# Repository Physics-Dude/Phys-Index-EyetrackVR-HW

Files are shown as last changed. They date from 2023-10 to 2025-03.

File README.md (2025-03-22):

# Phys-Index-EyetrackVR-HW
Custom solution for a clean, unobtrusive, EyeTrackVR installation in the **Valve Index**.  

### Project includes:
- Custom, highly iterated camera and LED mounts based on bitbyt3r's design that may be preferable to any builder. Supports most OV2640 cameras with an 8mm square, 2mm tall base.
- All-in-one dongle that carries a USB hub, 2x XIAO ESP32s, the ETVR v4 PCB, and an extra USB port.

Everything fits entirely within the envelope of the Valve Index. No modifications to the Valve Index headset are required whatsoever; just some clever cable routing. 

newnewnewnwe

### NEW! Gum Stick Remix (GSR) by Renzath
- Supports an aditional ESP for face tracking, and uses a different USB hub.
- Full writeup TBD

  Photo TBD

# Build the Original Gumstick Project! 

## Camera and LED mounts
An evolution of bitbyt3r's index-eyetrackvr mounts for the Valve Index found here: https://github.com/bitbyt3r/index-eyetrackvr  

cad-shot

Light pattern:


Files: https://github.com/Physics-Dude/Phys-Index-EyetrackVR-HW/tree/main/ETVR%20ValveIndex%20Cam-LED%20Mount%20Rings

### Changes:
- Lowered all leds 0.5mm further from face.
- Thickened up thin points near LEDs so they are FDM-printable in a single fill-line.
- Chamfers and fillets for strength and comfort.
- Tweaked the fit on the LED posts to prevent binding on solderless kits.
- Moved the camera up to the side of the eye.
- Moved the all the LEDs to a more optimal position to prevent specular reflections, shadows, and silhouetting.
### Tips:
- Print in black PETG
- Mirror the provided file for the opposite eye
- If you need to extend the wires a bit, stagger your cuts to prevent the joints from ever touching.

## Gum Stick USB Hub Dongle
Built around a specific ultra-slim 3-port USB hub. Fits two XIAO ESP32-S3s and a ETVR v4 PCB, as well as a spare USB port.

Files: https://github.com/Physics-Dude/Phys-Index-EyetrackVR-HW/tree/main/Gum%20Stick%20Dongle%20Custom%20USB%20Hub%20Case



### You need this specific USB hub (various brands)
Found on the likes of Amazon and Aliexpress. Its easy to modify for our purpose.



#### Common Titles:
- "USB Hub 3.0 Extender 3-Port, sartyee Computer Networking Hubs for MacBook, Mac Pro, iMac, Ps4/5, Surface Pro,Flash Drive, Keyboard, Mouse, Windows"
- "3 Ports Multiple Expander with 1 USB3.0 and 2 USB2.0 Ports Type-C3.0/USB3.0 To 3USB HUB Ultra Slim Splitter 480Mbps-5.0Gbps"
- "3 Port USB 3.0 USB Hub 2.0 Multi Type-C Ultra Slim Splitter Hub Use Power Adapter Multiple Expander 2.0 USB 3.0 Hub for PC"
#### Links:
- ~~Amazon: https://www.amazon.com/gp/product/B0BQ68QGYJ/~~ (Listing updated and now shows similar but different product.)
- Amazon: https://www.amazon.com/YaimhSound-Extender-Splitter-Extension-Keyborad/dp/B0BXJ21DXZ
- Aliexpress (choose the normal USB version): https://www.aliexpress.us/item/3256805344126437.html
#### Note/Avoid: 
- Avoid similar looking USB hubs with an LED indicator present between the two side-mounted ports. These likely won't fit since the PCB design on these seems to be flipped. If you do come across one such USB hub, consider using the (currently untested) no-spacer alternitive which gives you about 1mm of room to route soldered wires under the hub's PCB. [Gum Stick Dongle Custom USB Hub Case/No-Spacer alternate - XIAO-ESP32S3 ETVR v4 gum stick index mount v24.stl](https://github.com/Physics-Dude/Phys-Index-EyetrackVR-HW/blob/main/Gum%20Stick%20Dongle%20Custom%20USB%20Hub%20Case/No-Spacer%20alternate%20-%20XIAO-ESP32S3%20ETVR%2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) 

### You want these other parts too
- 2x XIAO ESP32-S3 Sense Modules - https://www.seeedstudio.com/XIAO-ESP32S3-Sense-p-5639.html
- 1x Solder-less V4 kit - https://store.eyetrackvr.dev/products/v4-mini-fully-solderless-kit
- Misc 28-32AWG wire for lengthening LED power wires
- 7x M2x5mm Countersink Self-tapping screws
- 2x OV2640 160 degrees night version camera module 200MM (select 200MM night vision) - https://www.aliexpress.us/item/3256803720134565.html - https://www.aliexpress.us/item/3256804483974787.html
  


Additional hardware options with more links available in the EyeTrackVR docs: https://docs.eyetrackvr.dev/how_to_build/parts_list

## Assemble it!
Follow the EyetrackVR docs for primary assembly and programming: https://docs.eyetrackvr.dev/how_to_build/full_build

Steps specific to the dongle are as follows.

### 1. Print 
- Print all 3 parts of the Gumstick in PETG
  - Files: https://github.com/Physics-Dude/Phys-Index-EyetrackVR-HW/tree/main/Gum%20Stick%20Dongle%20Custom%20USB%20Hub%20Case
- Print a Left and Right pair of the camera/LED mount rings if you have not already/
  - Files: https://github.com/Physics-Dude/Phys-Index-EyetrackVR-HW/tree/main/ETVR%20ValveIndex%20Cam-LED%20Mount%20Rings
- Refer or use the "PRINT ME" file for suggested orientations.
- ENABLE SUPPORT MATERIAL on build plate only.

### 2. Mod the USB hub
- Take the aforementioned USB hub apart (it slides out when you plug something in the end with a little force) and de-solder all the connectors. Save at least one of the small USB 2.0 ones.
- If the case is stuck, you may have to get a Dremel or some snips and nip away at the corners, careful not to cut the PCB. It is only glued near the input USB.
- I suggest using a hot air tool if possible to remove the connectors. Adding your own flux and leaded solder will make desoldering easier too regardless.

Untitled-1pin

### 3. Place
- Insert your dismantled USB hub into the dongle along with the spare USB port. Make sure you removed all the support material in that cavity. 
- Verify that your XIAO ESPs and ETVR v4 PCB fit in their slots. It may be tight, but if not, use adhesives. Careful not to crush the ESP's buttons or riser connector!
  


### 4. Solder
- Solder your VUSB, GND, D+ and D- wires to your ESPs now.
- Use the square ground pad on the bottom of the XIAO ESP for ground (not the GND pin on the edge of the board). 
- Observe the Connector orientation of the original USB hub and refrence it to a pin-out diagram of the USB A port. 
- Solder 2 wires to the bottom side of the ETVR v4 PCB for power. (and led wires for solder-kit)
- Route them like so and solder in place. A small hole will let you route the ETVR v4 PCB wires into the main cavity.
  



- quick wiring diagram to mitigate confusion


- Still confused? This diagram might help: https://github.com/Physics-Dude/Phys-Index-EyetrackVR-HW/issues/5#issuecomment-2413598211

### 6. LEDs!
- You will follow the instructions in the ETVR docs and lengthen a couple of the wires with 36-32awg wire.
- The long main feed wires get extended to about 200-250mm, while two of the shorter wires get extended to about 80mm.
- Tip: Stagger your cuts when lengthening your wires so the soldered ends can never touch.

- Once you verify everyhting is working 100%, it might be a good idea to remove the unused connectors on the E/End LEDs. You can do this with a pair of snips and a soldering iron with fresh solder.  



(early version of the modified mounts)


(latest version close up, installed )
anotehr-new-bpic

### 7. Cable Routing
- Your 200mm camera ribbons can be pushed up the "nose" of the headset and around the top of the PCB.

PXL_20231018_004047633s

- They may seem to interfere with IPD adjustment, but try folding them so they take a twist as they travel behind the PCB and between the screens. Keep in mind you may loose a couple millimeters of IPD due to the LED placement when using solder-less kit.
- Then they can be massaged through the vent holes in the frunk along with the extended LED power wires.



- It might help to gently fold your ribbon cable like so to get it to fit in the frunk vent holes. Note that some vent slots are blocked when assembled. 



- Pinch point! Watch here when the face pad is mounted. It's possible the ribbon cable can get trapped under this lip when adjusting screen-face distance. A small bend in the wire will teach it to stay away.
  
pibce 

- I also found that folding the camera ribbons like so can help teach them where to go.
  
teach

### 8. Finalizing
- Plug everything in and secure the optional covers with M2x5mm Countersink Self-tapping screws.
- P.S. Did you notice the holes for a 25mm fan? Is optional, but there if you want to keep your ESPs chilly.




- Use a Command Strip or piece of foam to ensure dongle does not come out during extreme VR stunts.
- Big nose? Consider removing the unused connector on the End LED if you expierence contact in that area. Felt may also be added for comfort.
nose-bridge

### Camera mount for Babble Face Tracking (uses same ESPs and Cameras)
- This part is in development, but working nicely from the start. You'll have to observe the pictures below to duplicate the build for your specific hardware.
- Files: https://github.com/Physics-Dude/Phys-Index-EyetrackVR-HW/tree/main/Babble%20Face%20Tracker%20Cam-LED%20Mount



extendd-mount


## In (experimental) summary:
- Use the same XIAO ESPs, with the same OpenIris firmware as the eye trackers.
- Use the same 200mm long OV2640 160 degrees night version IR camera module.
- Use two 3mm IR LEDs wired in series with a 100R resister on the 5v VBUS rail (use the 3V3 rail or a larger value resistor if you have more efficient LEDs). I sanded the lenses down on my leds for a wider, softer spread as well. 
- 3D print the print file in the Babble Face Tracker Cam-LED Mount folder with support material enabled. (EXTENDED version also available, print both to see what works for you)
- Stick camera mount base and cable clip to your Valve Index with double-sided VHB tape as shown.
- Use a 25mm countersink M3 screw with lock nut for the hinge.
- XIAO ESP can be placed at the end of the Gum Stick with more VBH tape.

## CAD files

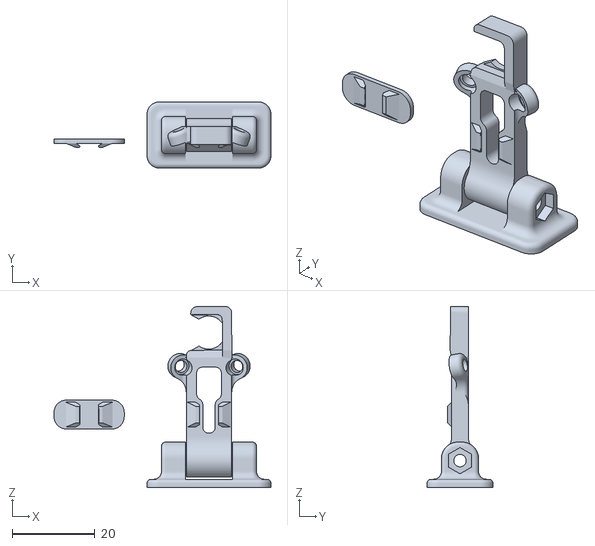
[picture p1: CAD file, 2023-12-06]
Babble Face Tracker Cam-LED Mount/FACE MOUNT v4 assembled.stl
52.5 x 16.0 x 43.8

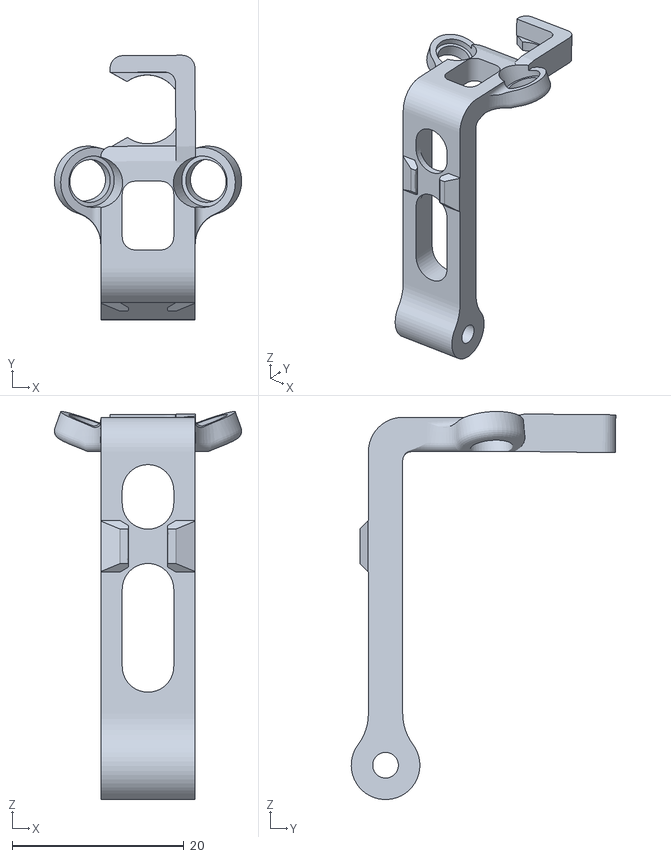
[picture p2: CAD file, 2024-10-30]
Babble Face Tracker Cam-LED Mount/EXTENDED Face Mount arm v5 - supports 5mm leds.stl.stl
21.8 x 30.8 x 45.2

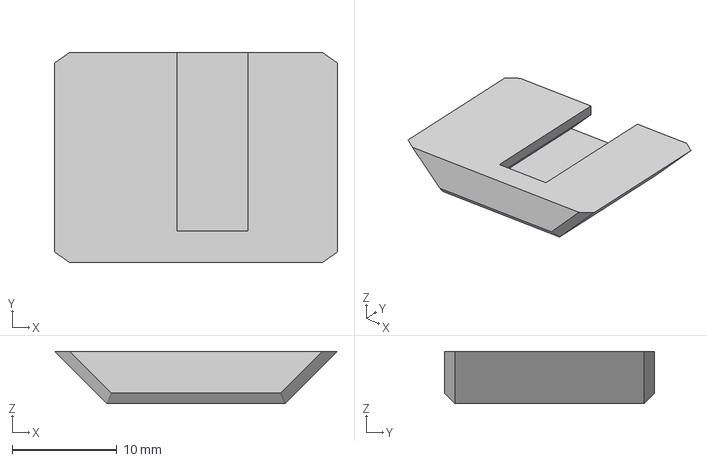
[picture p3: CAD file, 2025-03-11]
Babble Face Tracker Cam-LED Mount/Gumstick Remix Mount (Alternative)/GSR_Babble_FaceCam_Base.3mf
27.0 x 20.0 x 5.00 mm

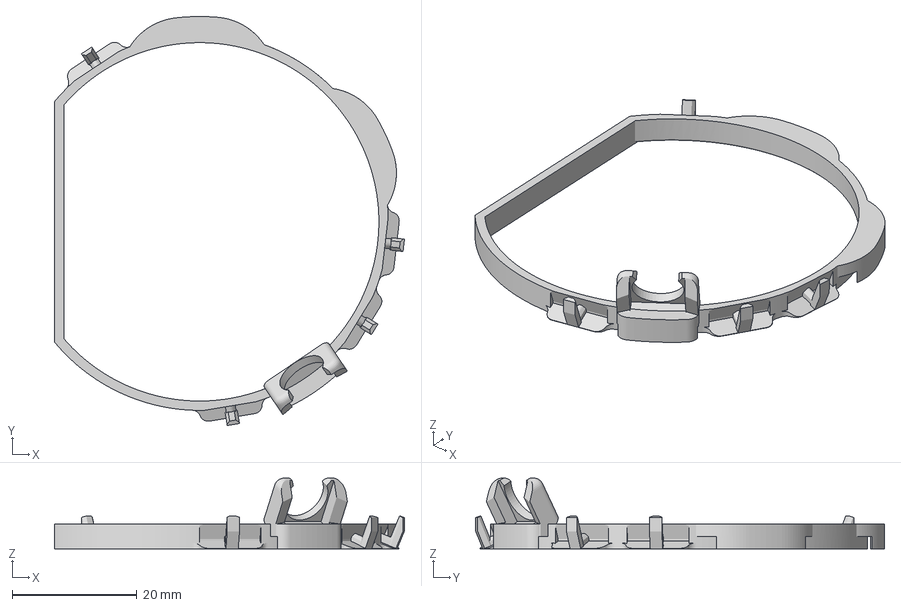
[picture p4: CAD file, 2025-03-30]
ETVR ValveIndex Cam-LED Mount Rings/Index-EyetrackVRv4 (GSR_Alt).3mf
56.2 x 65.6 x 11.3 mm

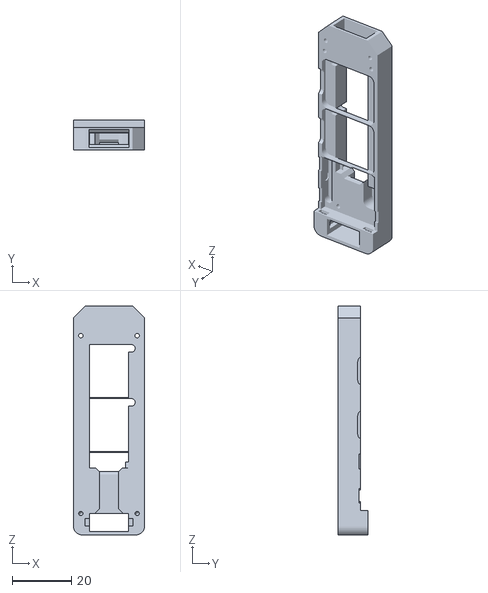
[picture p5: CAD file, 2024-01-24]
Gum Stick Dongle Custom USB Hub Case/No-Spacer alternate - XIAO-ESP32S3 ETVR v4 gum stick index mount v24.stl
24.0 x 10.0 x 77.2

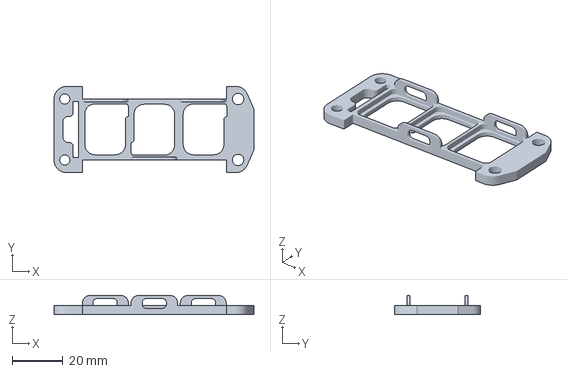
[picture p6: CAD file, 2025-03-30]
Gum Stick Remix for 3x ESPs plus USB Hub/Adafruit USB Hub (Latest Version)/GSR-Adafruit_ESP-Frame-Basic.3mf
78.8 x 34.0 x 7.50 mm

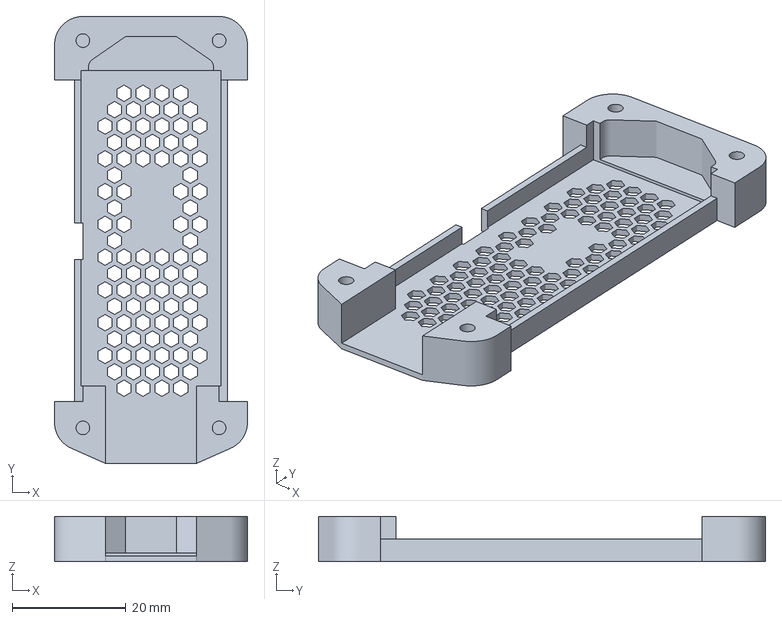
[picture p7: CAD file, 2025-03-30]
Gum Stick Remix for 3x ESPs plus USB Hub/Adafruit USB Hub (Latest Version)/Prototypes (Work In Progress)/GSR-Adafruit_THD-Base-Cover.3mf
34.0 x 78.8 x 8.00 mm

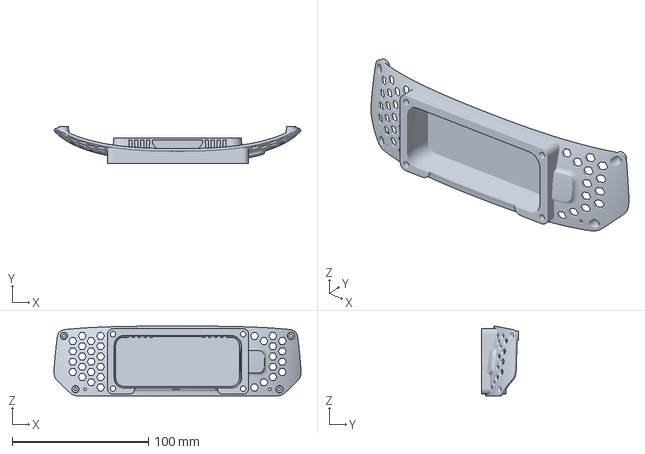
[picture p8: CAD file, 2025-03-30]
Gum Stick Remix for 3x ESPs plus USB Hub/Frunk Holder (Use M3x14mm Lid)/GSR-Frunk_Index-Frame.3mf
181.5 x 27.2 x 51.3 mm

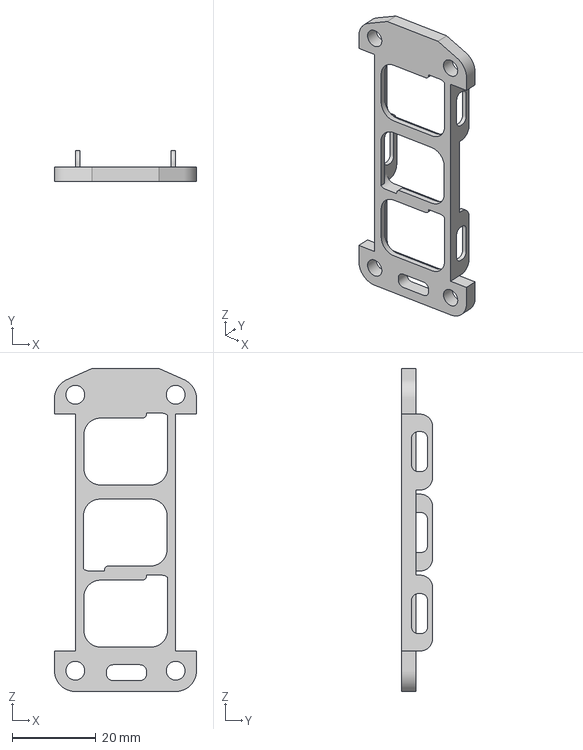
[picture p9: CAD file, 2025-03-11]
Gum Stick Remix for 3x ESPs plus USB Hub/Origional GSR Design (Cheap USB Hub)/GSR-Origional_ESP-Frame.3mf
34.0 x 7.50 x 77.3 mm

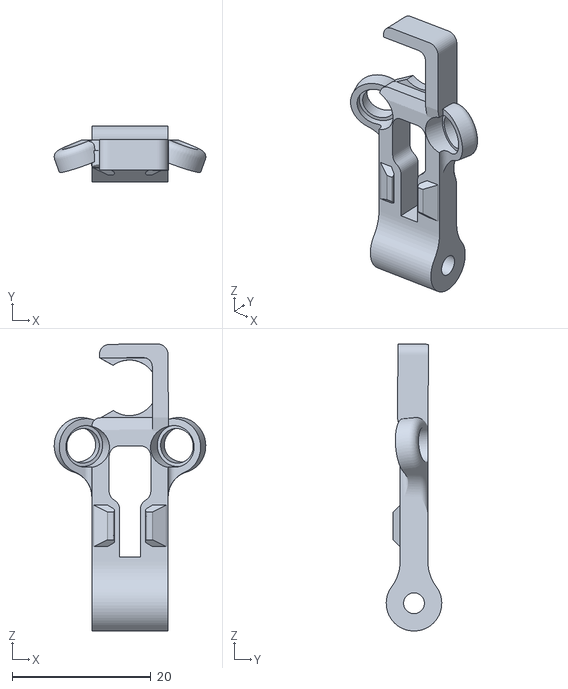
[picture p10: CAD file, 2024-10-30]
Babble Face Tracker Cam-LED Mount/Face Mount arm v5 - supports 5mm leds.stl
21.8 x 7.99 x 41.3

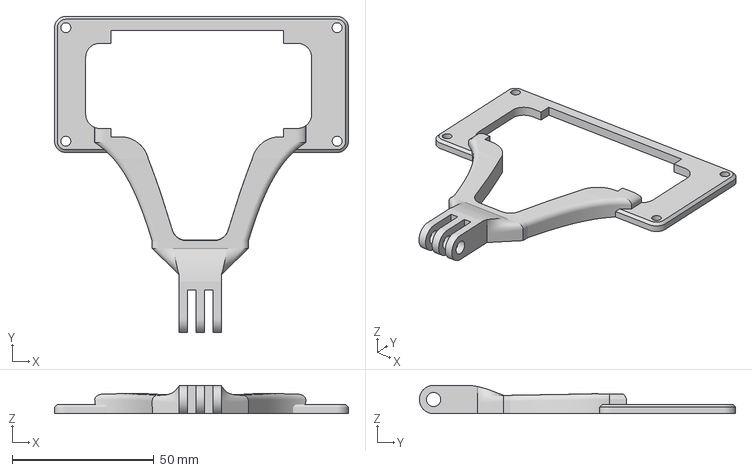
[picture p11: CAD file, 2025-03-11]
Babble Face Tracker Cam-LED Mount/Gumstick Remix Mount (Alternative)/GSR_Basic_FaceCam-Module.3mf
103.6 x 111.5 x 10.0 mm

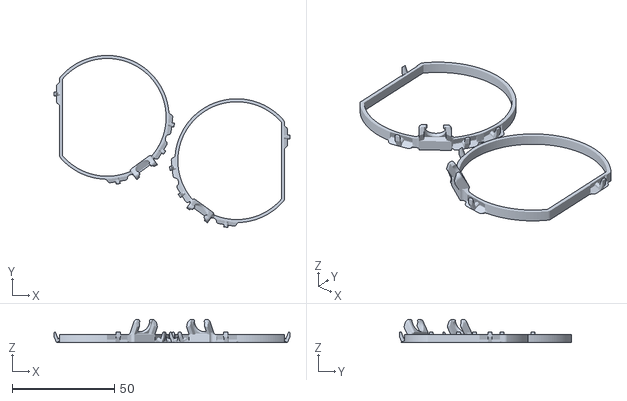
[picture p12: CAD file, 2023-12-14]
ETVR ValveIndex Cam-LED Mount Rings/Index-EyetrackVRv4 v18 combined L and R plate.stl
115.3 x 84.1 x 11.3

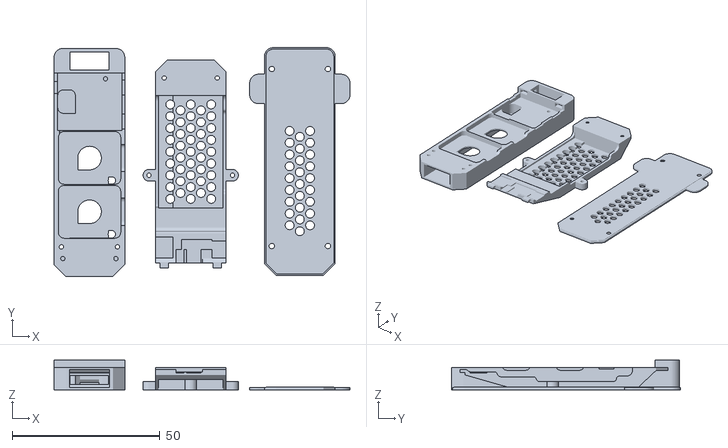
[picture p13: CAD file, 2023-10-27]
Gum Stick Dongle Custom USB Hub Case/XIAO-ESP32S3 ETVR v4 gum stick index mount v22 PRINT ME.stl
100.3 x 77.5 x 10.0

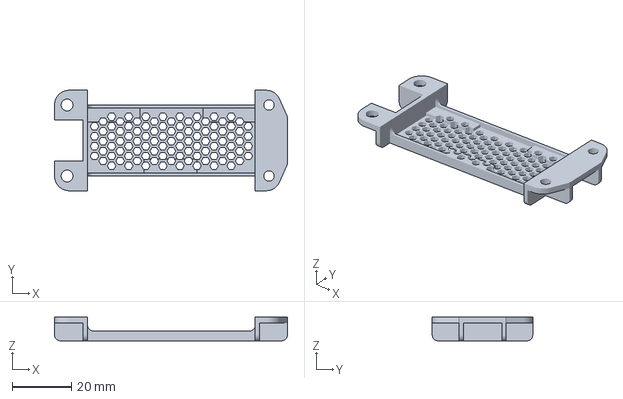
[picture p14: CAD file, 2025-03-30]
Gum Stick Remix for 3x ESPs plus USB Hub/Adafruit USB Hub (Latest Version)/GSR-Adafruit_Lid-Cover-USB (M3x14mm).3mf
78.8 x 34.0 x 8.00 mm

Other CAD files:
Gum Stick Remix for 3x ESPs plus USB Hub/Adafruit USB Hub (Latest Version)/Prototypes (Work In Progress)/GSR-Adafruit_Lid-Cover-USB (M3x20mm).3mf
Gum Stick Remix for 3x ESPs plus USB Hub/Frunk Holder (Use M3x14mm Lid)/GSR-Frunk_Brace_NoCam.3mf
Gum Stick Remix for 3x ESPs plus USB Hub/Origional GSR Design (Cheap USB Hub)/GSR-Origional_Hub-Frame.3mf
Babble Face Tracker Cam-LED Mount/EXTENDED Face Mount arm v4 PRINT ME.stl
Babble Face Tracker Cam-LED Mount/FACE MOUNT v4 - PRINT ME with support.stl
Babble Face Tracker Cam-LED Mount/Gumstick Remix Mount (Alternative)/GSR_Babble_FaceCam_Left.3mf
Babble Face Tracker Cam-LED Mount/Gumstick Remix Mount (Alternative)/GSR_Babble_FaceCam_Right.3mf
Babble Face Tracker Cam-LED Mount/Gumstick Remix Mount (Alternative)/GSR_Basic_FaceCam-Mount.3mf
ETVR ValveIndex Cam-LED Mount Rings/Index-EyetrackVRv4 (GSR_Alt).f3d
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

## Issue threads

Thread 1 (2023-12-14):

right eye print

rawpie2, 2023-12-14:
I only see left eye in the .stl files, where is the one to print for the right eye? thanks.

Physics-Dude, 2023-12-14:
You have to mirror the model in your slicer to print the right eye ring. (In Prusa Slicer for example, right click the part > Mirror > Mirror X).
This simplifies version control and encourages you to print one ring at a time which reduces stringing.

Physics-Dude, 2023-12-14:
I created [ETVR ValveIndex Cam-LED Mount Rings/Index-EyetrackVRv4 v18 combined L and R plate.stl](https://github.com/Physics-Dude/Phys-Index-EyetrackVR-HW/blob/d3e680a5e1266e084980f29253d3a4de4e84feea/ETVR%20ValveIndex%20Cam-LED%20Mount%20Rings/Index-EyetrackVRv4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) with both mirrored copies of the rings if desired. Just be careful on stringy printers.

Closed 2023-12-14.

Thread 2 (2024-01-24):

[Model question] "Inverted" gum stick model

tompointexe, 2024-01-24:
Hi, with the usb hub i got, mounting and solderiung would result in the boards beeing on the wrong side, do you have a model with is "inverted" from the curent one, see pics below
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

Thanks a lot

Physics-Dude, 2024-01-24:
That is weird. I've never came across that model of USB hub before. Do you have a link to the product pace so we can avoid that in the future? It looks like it has an LED in the middle which might be a good indicator for future product hunts.

A mirrored version wont work since all your solder pads will still effectively be on the wrong side of the USB hub's PCB. You might be better off soldering your thinnest wire (28-32AWG) to all the hub pads you'll need, then sliding it into the gum stick you already printed so those pads are effectively facing downwards and hidden.

Alternatively, here is a version of the hum stick that has the spacer between the ESPs and USB hub PCB removed. This should give you more room for the soldered pads and wire to snake out from under the usb hub's pcb and into the cavity for later connection to the ESPs. I'd suggest a strip of tape on the ESPs though to prevent any shorts if you dont trust your soldering.

[No-Spacer alternate - XIAO-ESP32S3 ETVR v4 gum stick index mount v24.stl](https://github.com/Physics-Dude/Phys-Index-EyetrackVR-HW/blob/main/Gum%20Stick%20Dongle%20Custom%20USB%20Hub%20Case/No-Spacer%20alternate%20-%20XIAO-ESP32S3%20ETVR%2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)

Keep us updated so we can mention it in the doc.

tompointexe, 2024-01-24:
Yup inverted is not realy the term, it would need to have the pcb insert and usb port where the front facing usb port is, and put that where the curent hub pcb insert is
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

The hub i've used is this one, it's the only one i could find on amazon.fr / Europe, i've not searched aliexpress tho
https://www.amazon.fr/dp/B0CLY9KZ68?

Physics-Dude, 2024-01-24:
The way I understand it, flipping the whole gum stick model on X or Y, (or inserting the hub from the other direction as per your initial edit) will not expose the HUB's solder pads since those are referenced to the orientation of the main USB port that plugs into the headset.

I would personally buy the correct hub from aliexpress. Re-mounting the main port sounds too invasive considering its molded into plastic from the factory.

The No-Spacer alternate body I linked previously does give you about 1mm of room to solder and route wires from 'under' the usb hub pcb to anywhere else in the cavity of the gum stick (as long as you solder the wires before inserting the hub into the main body of the gum stick with the corrected orientation). If you got the time waiting for a new hub, I'd still try this so at least you'd have a working spare if it doesn't work out.

I'll put a note in the readme to avoid the similar-looking USB hubs with LED indicators.

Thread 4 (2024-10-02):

(tweak) Please consider adding a license

dfgHiatus, 2024-10-02:
I am thinking of using the Babble 3D models for an assembly animation. I wanted to confirm this was suitable with you for our use case.

Physics-Dude, 2024-10-02:
Sounds cool to me! Go for it.
I'll go ahead and add the MIT License unless someone has an alternate suggestion.

Physics-Dude, 2024-10-02:
added https://github.com/Physics-Dude/Phys-Index-EyetrackVR-HW/blob/main/LICENSE

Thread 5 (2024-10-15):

confused about the soldering

fleufy, 2024-10-15:
Hi! It's my first time doing this sort of thing, I've never soldered or done any type of electronics before, sorry if I'm just being stupid!
I just started the soldering steps and wired everything (shown in the picture) but I messed something up.
I thought I had to solder both of the ESPs in the same places but your photo shows the wires of the ETVR connected to the soldering pads that (I thought) were reserved for the 2nd ESP.
Now I'm not sure what to do with my wires, if you could help me, it would mean the world!
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

Physics-Dude, 2024-10-15:
Hi, your build is looking good and that is a great question. The two wires from the ETVE LED driver board are supposed to share any 5v and Gnd pad on the USB hub. I should have made this more clear in the guide, but here is a picture that may help.

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

If it works for you, I may include this pic in the main write-up. Let us know if you have any more questions.

fleufy, 2024-10-15:
Thank you very much! That absolutely solves my issue. Have a great day!

Closed 2024-10-15.

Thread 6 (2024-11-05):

USB Hub Requirement confusing cased me to get the wrong one

AAMBIENTT, 2024-11-05:
Would like to point out the usb hub in the image of the guide is one you DONT want us to buy. That has the LED and is too short for all of the adapters. Please use an image like this one to tell us what to look for
Wrong: https://www.amazon.com/Aluminium-Splitter-Expander-Console-Keyborad/dp/B0BJZ753D9
Right: https://www.amazon.com/YaimhSound-Extender-Splitter-Extension-Keyborad/dp/B0BXJ21DXZ

Physics-Dude, 2024-11-05:
You are right, the listing has changed. I will update the writeup now.
(i will also strike out the old one just in case it is a temporary amazon change.)

AAMBIENTT, 2024-11-06:
could you please update the image as well, as that model in the image is the one i purchased and it was very wrong.

Physics-Dude, 2024-11-06:
done! there is also a gum stick frame variant that should allow for the flipped hub design as well.

Closed 2024-11-05.

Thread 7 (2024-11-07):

ETVR v4 PCB Wiring diagram missing

AAMBIENTT, 2024-11-07:
the ETVR v4 PCB Wiring diagram is missing. Currently at the step of wiring everything together and i cannot figure out how to wire in the ETVR v4 PCB.

Physics-Dude, 2024-11-07:
I unfortunately do not have any pictures of the underside of my vr board, but in summery:

1. Solder two wires to the "VIN" + and - pins
2. Feed them through the little hole that goes from the ETVR pcb area, to the USB hub area (you can see these purple/black wires in the writeup)
3. Solder these respective + and - wires to any 5v and GND pads on the USB hub. You can share the same pins any ESPs is using for power.

let me know if this helps and i can include it in the write up.

AAMBIENTT, 2024-11-07:
Perfect, will try once i receive the correct hub in the mail, i will take as many images as possible for you here

AAMBIENTT, 2024-12-16:
Ok, so im having an issue with the et r module of when the power switch is set to on, i get an error in windows mentioning theres a power surge and it exceeds the power limit of the hub. Any fix?

Physics-Dude, 2024-12-16:
That means there is a short circuit or solder bridge somewhere between VUSB and Gnd. You should inspect all your soldered connections and make sure everything is soldered to the right places. Also make sure no solder or pieces of wire is touching places it shouldn't.

AAMBIENTT, 2024-12-16:
Ok, so i think i got it, but im not sure how to test to make sure that the LEDs and etvr board are working. Is there any way to test these to see if they appear?

AAMBIENTT, 2024-12-16:
I dont seem to see any leds.

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

Physics-Dude, 2024-12-16:
Check out the ETVR Discord server. The search bar can give you a trove of past fixes and pictures. and lots of people there can help.

https://discord.gg/kkXYbVykZX

Closed 2024-12-16.

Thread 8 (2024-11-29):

Mouth Tracker Wiring diagram needed

AAMBIENTT, 2024-11-29:
I saw you mentioned we needed resitors. i have one here but i do not see where you have yours hidden here. is it truly needed?

Physics-Dude, 2024-11-29:
A resistor is indeed needed in most cases, but the value is dependent on the particular IR LEDs you chose.

With two series 1.6v, 20mA IR LEDs I used, a 100 ohm series resistor was required.

In my case, I hid the resistor under the camera ribbon between the two LEDs on the face camera arm. You can also solder it to the 5v vbus pin, just make sure it doesnt short out to other parts of the ESP.

if this helps, let me know. I was thinking about adding a FAQ to the write up. 👍

AAMBIENTT, 2024-12-16:
I was reading the guide while wrapping this up and ended up removing one of the pads from one of my esps (data+) so i was just going to plug the usb into the c port of the esp, but will that still deliver power to the 5v rail on the board? Will that provide power even if its powered through the c port

Physics-Dude, 2024-12-16:
Yes, you can connect any of the same pads from a USB-C breakout connector to where they would go on the USB hub. You can use any combination of pads and plug wires (i.e. use VUSB and Gnd where they normally go, and D- and D+ from the usb connector you add).

AAMBIENTT, 2024-12-17:
Ok so i think this will be our final interaction! Everything is done and wired, however, the mouth LEDs appear to be super dim. I have it wired as such
VBUS>100r>3mm 940nm Emitter #1 Anode->3mm 940nm Emitter #1 Cathode>3mm 940nm Emitter #2 Anode->3mm 940nm Emitter #2 Cathode>GND

Is this right? As mentioned, it is incredibly dim.

Physics-Dude, 2024-12-17:
Your circuit is correct, but due to the variety of IR LEDs out there, its a guessing game for finding the resistor value. If your source of LEDs tells you the max volts/current value on the product page, use that in a "LED Series Resistor Calculator".

If the image from the camera is still dark while mounted to your headset and pointed at your face, it is safe to assume you can lower your resistor value slightly to increase brightness. Check the Project Babble docs or Discord server for references on how dark/bright the image should be.  https://discord.gg/c99B6vB2sX

I would try a 75 ohm resistor next, then a 50 ohm after that if it is still too dark.

Closed 2024-12-17.

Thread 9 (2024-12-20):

Question on all Hardware Needed

Keyrehn, 2024-12-20:
Think I bought everything for the eye tracking setup. but what I needed help with is a list of all the things I need. since I'm not sure I have everything required for the Camera Mount for Babble Face Tracking i.e.

2x of this
1x of that

Thanks in advance.

Physics-Dude, 2024-12-20:
Do you mean two IR LEDs and one resistor?

I leave it ambiguous since there's many sources of IR LEDs and some sources have different brightness/efficiency and therefore require a different value of resistor for 5v.
My camera mount now supports 3mm OR 5mm LEDs, so the size of the LED doesn't matter as much anymore.

Most seem to get it working with generic IR LEDs from Amazon in series with a 75 ohm resistor. If the image is too bright or too dark, adjust the resistor up or down to either 100 or 50 ohm respectively. These are all common values of resistor and usually included in resistor assortment kits.

Consult a Series LED Resistor Calculator given your specific LEDs' product page.

Adafruit is also a source for really nice, efficient, and super bright IR LEDS.

Everything else required for the face camera is just a duplicate of any of the ETVR eye hardware, minus the USB hub or led boards. (so the same camera, and an ESP XIAO S3). A short (usually DIY) usb cable for this ESP is also needed and plugs into the unused port in the gumstick.

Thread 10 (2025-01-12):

Face tracker mount; LED safety/supply question

Datgek, 2025-01-12:
Asking this because I'm not very mathematically skilled and have 0 experience when messing around with LEDs.
(I know I'm probably just over complicating this on my end, but I'd rather ask an unnecessary question than risk blinding myself.)
(And if the answer is just, "go on amazon, it's most likely fine" that'd be good too lol.)

The ETVR website, under "LED Safety", lists the equation for a light's radiance as "mW/cm2/sr" I believe that I understand the equation correctly, but I'm having trouble figuring out how to get the mW as needed for it. As well as figuring out the "sr" portion.

By my understanding, getting the mW listed in the equation is done with LEDs supplied voltage, minus the forward voltage per each LED wired in series(?), then divided by the resistor's ohm rating.
The only issue I'm having (and it might not even be an issue), is that for any LED I put into a resistor calculator, the outputted resistance seems lower than expected, such as the addicore 5mm IR LEDs, the resistance when calculated with 2 LEDs is 18 ohm, which just seems way too low to me...

I. . . have been flipping through so many tabs to double check my numbers and logic while typing this that I forgot what my original point was...  but just in general, what would I need to look out for so that I don't cause damage to anything, and/or am I just over complicating this like crazy?

Physics-Dude, 2025-01-13:
Don't confuse an LED's light irradiance (mw/cm^2) with its power consumption (mW), these are very different numbers.

Power consumption (mW) is defined by the LEDs rated forward voltage (typically between 1.2v to 1.6v for IR leds) multiplied by the forward current (typically 30-50mA). Your supply voltage is always going to be about 5v here.

Resistor = (Supply Voltage / LED Voltage) / (LED Current)

Most 3mm and 5mm IR LEDs I seen have a 1.2v forward voltage, and 30mA current limit. You'll usually need two of these.
Two in series are equivalent to a 2.4v led at 30mA. This pair would require a 100 ohm resistor if supplied by 5v.

Adafruit sells a nice efficient set of 5mm LEDs that are 1.6v and 100mA. You dont need this to be full power, it will be too bright on the camera, so its best to 'dim' it by pretending its a 50mA LED or so.

As for safety;

LED safety is only considered when non-visible light is shining directly into the eye balls as there is existing research concerning that. LEDs of this scale shining on skin are far less concerning (some peer reviewed sources even indicate it is beneficial to an extent, but thats beyond this scope).

For the LEDs in the eye-tracking rings, I can only suggest the official ETVR kits in full.

For selecting the LEDs in the face tracker, due to the variance in LED sources and user choice, the best thing you can do is test with a high value resistor (i.e. 220 ohm) then work your way down in standard increments. (I.e. 150, 100, 75, 47, 22) looking at your camera feed while everything is mounted and see if your face is too light/dark. nothing in this range at 5v is considered dangerous to bare skin.

Worst case, if you go too low on the resistor and make the led shine brighter than it was designed to, it'll be hot to touch and you'll burn it out.

Datgek, 2025-01-13:
Ok, I'm realizing now that I was operating under the pretense that, if I were to try and run an LED at a current lower then it's listed forward current, it simply wouldn't work, this explanation though was better than 90% of the info I found online.

As for the Adafruit LED, I did come across it while looking, but alongside the aforementioned pretense (thinking that it'd only function at 100+mA), it was also listed as 940nm, so I wasn't sure if it wouldn't show as well on a 850nm camera.

All in all though, thank you for the (_actually_ easy to understand) explanation.

Closed 2025-01-13.

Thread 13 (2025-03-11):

Wire Routing

MrVampy99, 2025-03-11:
I am unsure on where to solder the power connections for the ETVR v4 PCB as I am new to electronics. Any help would be nice

Physics-Dude, 2025-03-11:
On the bottom of the v4 PCB, the VIN + pad connects to any positive 5v pin on the usb hub. This is the same spot any ESP's VUSB pin connects to.

The VIN - pin on the bottom of the ETVR v4 PCB connects to any Gnd pin on the USB hub. You can share the same pad that any Gnd pin any ESP connects to.

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

Marokarr, 2025-03-13:
Can the 5V VIN+ pad that is already supplying power to the ESP32 also be used at the same time to power the v4 PCB?

Physics-Dude, 2025-03-13:
yes

Closed 2025-03-12.

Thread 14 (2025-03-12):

Not all IR lights work

MrVampy99, 2025-03-12:
Ive tried switching the two plugs and i got the same results on the same lights.

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

Physics-Dude, 2025-03-12:
It would be best to take this up with the EyeTrackVR Discord.

It is likely yo have the E/End boards in the wrong place.

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

Closed 2025-03-12.

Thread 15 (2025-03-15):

What do we do if there are no 200mm OV2640 modules available anywhere at all?

TheSpiderDungeon, 2025-03-15:
Does it have to be _EXACTLY_ 160 degrees? Can it be 75mm long? Because I've checked 12 sites and none of them have both 200mm _and_ 160 degree FOV.

Physics-Dude, 2025-03-15:
Many have resorted to getting the 24-pin Extension ribbon and Extension connector when the 200mm cameras are unavailable. Both available on Aliexpress and Adafruit.

https://docs.eyetrackvr.dev/how_to_build/part_list

GarnetSunset, 2025-04-15:
For anyone lost in the sauce like me:
https://www.aliexpress.us/item/3256802853835121.html
Color: 75MM-160 850nm

and
https://www.aliexpress.us/item/2255799835842411.html
200mm A , Insert Type: 24p 0.5mm pitch

Physics-Dude, 2025-04-16:
Don't forget the female-female extension connector so you can connect the camera ribbon to the extension ribbon:

https://www.aliexpress.us/item/3256804096715690.html
Click: 24 pin

GarnetSunset, 2025-04-16:
Bought, thank you!

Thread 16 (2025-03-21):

What's the Difference in steps if we use the V4 mini Solder Required LED Kit?

xlDarkDragonlx, 2025-03-21:
Im really new to modding vr but im going to be following the guide with my step dad and i was wondering what the difference would be if we used V4 mini Solder Required LED Kit instead of the no solder cause it is currently sold out, and since i have you here i also pre ordered a babble facial tracker will this block the mount for that too or will i have to print my own mount for it

Physics-Dude, 2025-03-21:
The solder-required ETVR v4 kit just means you have to supply your own 28-32AWG solid core wire and solder to the pads on the respective leds and power PCB. The ETVR discord can answer any more questions.

It looks like the "replacement wires" are in stock on the ETVR store. I would buy a couple of those to make life easier.

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

Physics-Dude, 2025-03-21:
I am 99% sure the solder-required kit still has the connectors installed on the PCBs. The pads you would solder to are on the underside of the PCB where the power input pads are.

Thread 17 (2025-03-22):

Question about Gum Stick Remix for 3x ESPs plus USB Hub

Marokarr, 2025-03-22:
Do you know if any of these are still using the same USB hub that you are recommending? or is it different.

Physics-Dude, 2025-03-22:
The Gum Stick Remix was built on the work of Renzath on the EyeTrackVR discord. He is currently working on a writeup with parts list. It is in beta, but there is a thread in the ETVR discord.

In short, I believe the hub for the GSR is one from Adafruit.

Closed 2025-03-22.

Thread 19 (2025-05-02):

About Babble

Bizbon3, 2025-05-02:
It might be my age, but do you or can you make a wiring diagram for that? When looking at the pictures, do you have both LEDs on the same circuit? so its sensor -> resister -> LED1 -> LED2 -> GRD is that correct?

Physics-Dude, 2025-05-03:
Yes, the two series IR LEDs for the Babble camera are in series with a 100 Ohm resistor (or whatever value suits your LEDs). These get power supplied between VUSB (aka USB +5 volts) and GND.

So its (+)5V ----> [Resistor] ----> [LED1 Anode] → [LED1 Cathode] ----> [LED2 Anode] → [LED2 Cathode] ----> GND

The resistor can go anywhere in the series circuit. IIRC, mine is placed between the two LEDs just for ease of installation.

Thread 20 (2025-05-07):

Curious about compatibility with prescription inserts

TrebleSketch, 2025-05-07:
Thinking about giving this a crack before Furality, was wondering if this project is compatible with the prescription insets from [VROptician](https://vroptician.com/prescription-lens-inserts/valve-index)?

If not, what would further modifications would be reququired to get this working if at all? (Somehow hooking onto the prescriotion lens frame itself?)

Physics-Dude, 2025-05-07:
Plenty of people have used prescription insets with ETVR on index. However I have only passively followed the development. For that, you should consult the official ETVR Discord server. Files are usually shared and iterated upon there. I'm sure there's a few public repos with comfortable camera + led + inset mounts by now they could link to.

Physics-Dude, 2025-05-22:
the 3mf files are designed to open only in Autodesk Fusion 360. You can use it for free as a hobbyist.

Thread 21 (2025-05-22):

Curious about how you wired the 3rd XIAO ESP32S3 For Mouth Tracking

toofast1313, 2025-05-22:
From the picture it looks like you have the 3rd XIAO ESP32S3 For Mouth Tracking. With 4 cables going into a USB Type A?

Same type of concept like the picture you provided for the USB Stick

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

Same concept just with a Male USB Type A wired to the XIAO ESP32S3?

I am curious cause I have all the parts ordered besides the 3D Printed parts, and lastly need the Male Type A part for the mouth tracking as well and thats it. So I am curious if my assumptions are correct and what the exact part is for the Male USB Type A?

Physics-Dude, 2025-05-22:
Yes, in my normal design, the mouth tracking ESP32 is soldered to a short wire that is in turn soldered to a male USB-A plug. The ESP itself is tucked inside the frunk, at the end of the gum stick. The USB-A plug is plugged into the extra usb port inside the gumstick and extended from the hub. (it also only needs the four USB 2.0 wires, 5v, d+, d-, gnd).

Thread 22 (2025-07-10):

Question about D- and + pad.

Jinxatron, 2025-07-10:
Hello, I received the parts for the kit; however, I've encountered some issues. The Digital pads on the back of the 32S3 didn't seem to stick when soldering, and when I finally achieved a good bond, they ripped. Now I assume the board is toast at this point, but I figured I'd ask if there is anywhere you could reroute those wires?

Fixing the trace is a no-go since I simply don't have the equipment, nor can I see where the signals go on the board.

Physics-Dude, 2025-07-11:
You might be able to use a simple USB-C (2.0) breakout with some modification to the gumstick case.
But if solder isn't sticking to the pads it could be:

1. Your solder does not have flux/rozen built in (aka rozen core solder). Use flux in addition to it, or get rozen core 60/40 solder.
2. Soldering iron is too hot/cold. Try 300ºC for 60/40 leaded solder.

Jinxatron, 2025-07-11:
You know, that is a very simple yet effective way to solve it. I will look into it, at first glance it just looks like I need to add some channels on the side for the cables.

and I deffo think I was running the solder to hot, after some research it seems delamination happened.

Jinxatron, 2025-07-11:
Yeupp. Impatience is expensive in the long run. Thank you for all the tips, it should come in handy. And thank you for designing this, much preferable over replacing the entire front.

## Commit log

2023-10-19 added fan mount and anti-rattle tabs
    [XIAO-ESP32S3 ETVR v4 gum stick index mount v15 PRINT ME.stl, XIAO-ESP32S3 ETVR v4 gum stick index mount v15.3mf, XIAO-ESP32S3 ETVR v4 gum stick index mount v15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]
2023-10-19 Update README.md
    updated for latest led ring
2023-10-19 iteration of camera and LED placements
    [Index-EyetrackVRv4 v12.3mf, Index-EyetrackVRv4 v12.f3d, Index-EyetrackVRv4 v12.step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]
2023-10-19 iteration of led and camera position
    [Index-EyetrackVRv4 v12.3mf, Index-EyetrackVRv4 v12.f3d, Index-EyetrackVRv4 v12.step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]
2023-10-19 iteration of led mounts
    fills shadow by the nose
    [Index-EyetrackVRv4 v13.3mf, Index-EyetrackVRv4 v13.f3d, Index-EyetrackVRv4 v13.step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]
2023-10-19 added NetFab repaired file for easy printing
    [Index-EyetrackVRv4 v13 NetFab Repaired.stl]
2023-10-19 Update README.md
    new photos of latest led mounts!
2023-10-20 added a relief for ribbon cable
    [Index-EyetrackVRv4 v18 Netfab Repaired.stl, Index-EyetrackVRv4 v18.3mf, Index-EyetrackVRv4 v18.f3d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]
2023-10-22 improved printability
    added chamfers to blind screw holes to prevent difficult to remove support material from forming.
    [XIAO-ESP32S3 ETVR v4 gum stick index mount v18 PRINT ME.stl, XIAO-ESP32S3 ETVR v4 gum stick index mount v18.3mf, XIAO-ESP32S3 ETVR v4 gum stick index mount v18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]
2023-10-23 Clearence to allow use of USB 3.0 jack
    [XIAO-ESP32S3 ETVR v4 gum stick index mount v19.3mf, XIAO-ESP32S3 ETVR v4 gum stick index mount v19.f3d, XIAO-ESP32S3 ETVR v4 gum stick index mount v19.step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]
2023-10-23 fixed clearence to allow use of USB 3.0 jack
    [XIAO-ESP32S3 ETVR v4 gum stick index mount v20-PRINT_ME.stl, XIAO-ESP32S3 ETVR v4 gum stick index mount v20.3mf, XIAO-ESP32S3 ETVR v4 gum stick index mount v20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]
2023-10-27 added "print me" stl file
    [Index-EyetrackVRv4 v18 Print Me.stl]
2023-10-27 improved printability
    [XIAO-ESP32S3 ETVR v4 gum stick index mount v22 PRINT ME.stl, XIAO-ESP32S3 ETVR v4 gum stick index mount v22.3mf, XIAO-ESP32S3 ETVR v4 gum stick index mount v22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]
2023-12-06 Added files for OV2640 camera+LED mount for Babble
    [FACE MOUNT v4 - PRINT ME with support.stl, FACE MOUNT v4.stl]
2023-12-06 added babble face tracking camera mod photos and text
2023-12-08 added words and pictures featuring extended face mount
2023-12-08 added extended face cam mount
    [EXTENDED Face Mount PRINT ME.stl]
2023-12-14 added dual eye piece plate for printing
    [Index-EyetrackVRv4 v18 combined L and R plate.stl]
2024-01-24 Added alt version for weird USB Hubs
    0.8mm spacer between ESPs and USB hub was removed to allow for solder pads to be on the other side of the hub's PCB.
    [No-Spacer alternate - XIAO-ESP32S3 ETVR v4 gum stick index mount v24.stl]
2024-07-18 Update README.md
    Now mentions optional 25mm fan
2024-09-30 Uploaded latest working release models for Gumstick Remix V1
    [EyeTrack-VR Gumstick Remix (ALL).3mf, EyeTrack-VR Gumstick Remix Base.3mf, EyeTrack-VR Gumstick Remix Cover.3mf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]
2024-10-30 Rename FACE MOUNT v4.stl to FACE MOUNT v4 assembled.stl
    [FACE MOUNT v4 assembled.stl]
2024-10-30 Rename EXTENDED Face Mount PRINT ME.stl to EXTENDED Face Mount arm v4 PRINT ME.stl
    [EXTENDED Face Mount arm v4 PRINT ME.stl]
2024-10-30 Added support for 5mm leds
    [EXTENDED Face Mount arm v5 - supports 5mm leds.stl.stl, Face Mount arm v5 - supports 5mm leds.stl]
2025-01-28 Updated ALL 3D Print Model Files and added Adafruit USB Hub Version
    [EyeTrack-VR Gumstick Remix (ALL).3mf, EyeTrack-VR Gumstick Remix Base.3mf, EyeTrack-VR Gumstick Remix Cover.3mf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]
2025-03-05 Included Index Frunk and GSRv2 brace with Mouth Cam holder option
    [Frunk Base Cam.3mf, Frunk Base Frame.3mf, Frunk Base Lid.3mf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]
2025-03-11 GSR Babble face cam module added and all files restructured for easy ref
    [EXTENDED Face Mount PRINT ME.stl, FACE MOUNT v4 - PRINT ME with support.stl, FACE MOUNT v4.stl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]
2025-03-11 Latest GSRv2 (Alternative Design) files updated
    [FACE MOUNT v4 - PRINT ME with support.stl, GSR_Babble_FaceCam_Base.3mf, GSR_Babble_FaceCam_Left.3mf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]
2025-03-18 GSR update adds alternative ETVR Lens Frames
    [Index-EyetrackVRv4 (GSR_Alt).3mf, Index-EyetrackVRv4 (GSR_Alt).f3d]
2025-03-29 GSR frame update for Adafruit 4090 USB-C Breakout board
    [GSR-Adafruit_ESP-Frame-Basic.3mf, GSR-Adafruit_ESP-Frame-Strong.3mf, GSR-Adafruit_ESP-Frame.3mf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]
